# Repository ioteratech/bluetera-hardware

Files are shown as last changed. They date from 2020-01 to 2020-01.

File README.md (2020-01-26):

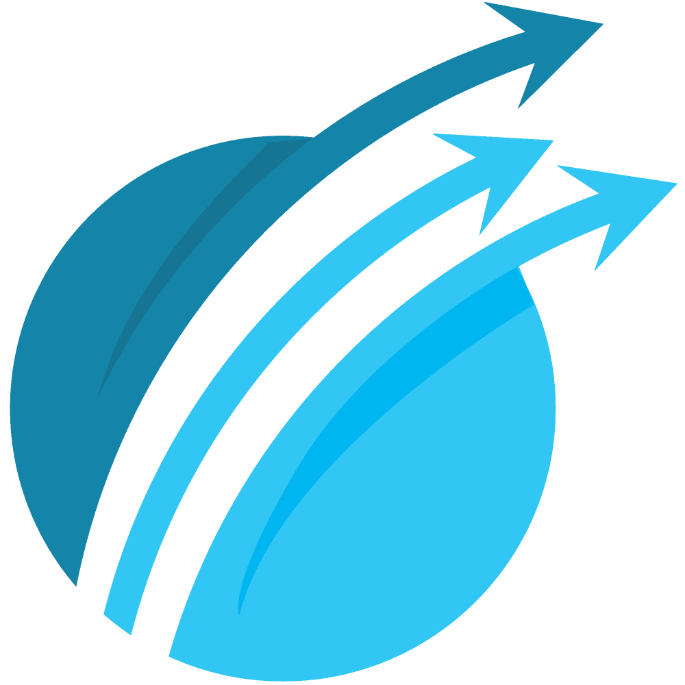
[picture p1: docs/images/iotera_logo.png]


# Bluetera Hardware

This repository contains the KiCad project for the Bluetera II and it's breakout adapter.

Bluetera is an open source IoT platform for the development of smart and connected products. The platform includes:
* Bluetera Hardware module (this repository)
* Bluetera Firmware - repository [here](https://github.com/ioteratech/bluetera-firmware)
* Blutera SDK(s) - repositories [here](https://github.com/ioteratech/)

More info available at our website: https://ioteratech.com

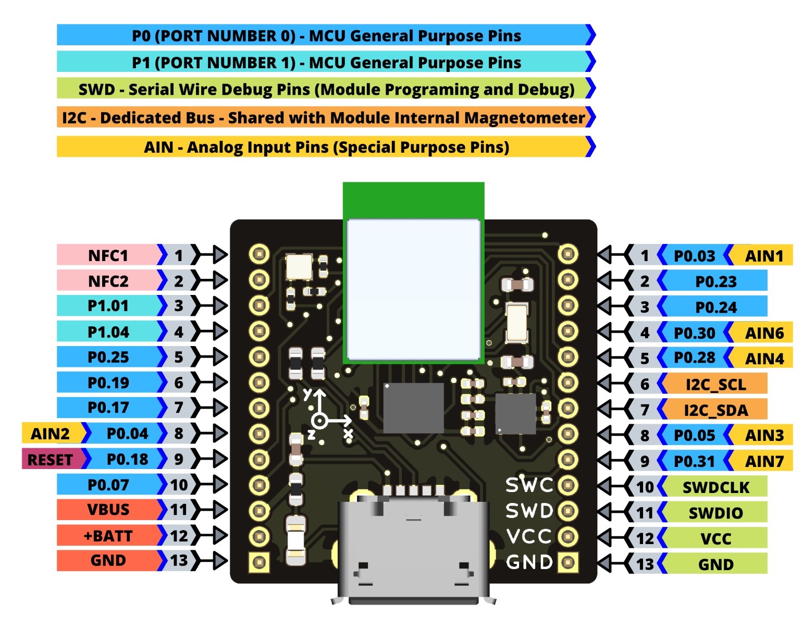
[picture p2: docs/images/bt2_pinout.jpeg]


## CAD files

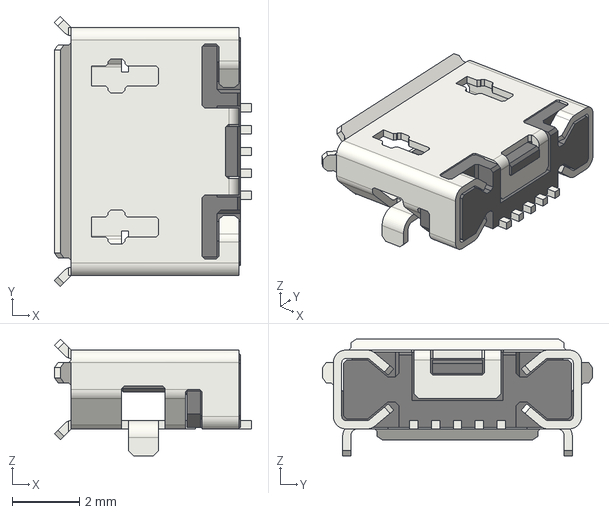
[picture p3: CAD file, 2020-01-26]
3d/Conn_USB-micro-2.0_socket_right-angle.step
5.88 x 8.05 x 3.47 mm

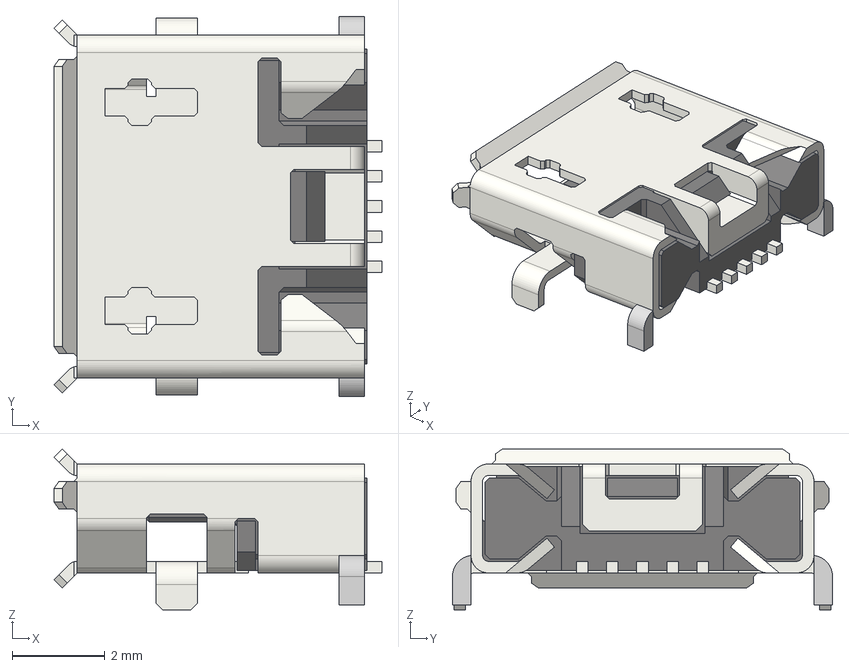
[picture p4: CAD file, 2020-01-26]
3d/Conn_USB-micro-2.step
7.07 x 8.20 x 3.47 mm

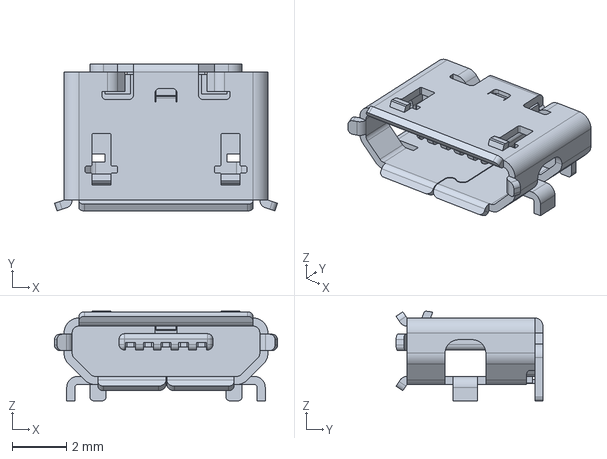
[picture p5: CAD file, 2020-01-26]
3d/Molex_Mirco_USB_105017-0001.step
8.20 x 5.40 x 3.30 mm

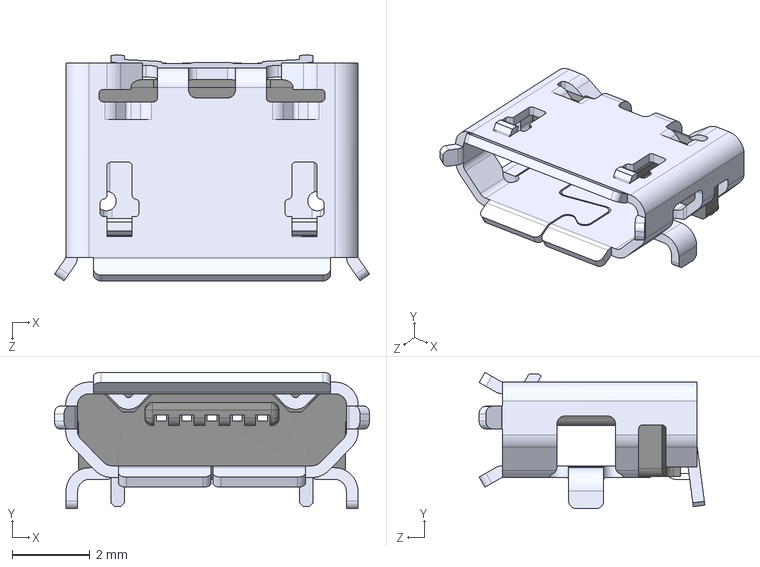
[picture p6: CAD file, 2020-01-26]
3d/ZX62D-B-5P8--3DModel-STEP-56544.STEP
8.09 x 3.50 x 5.80 mm

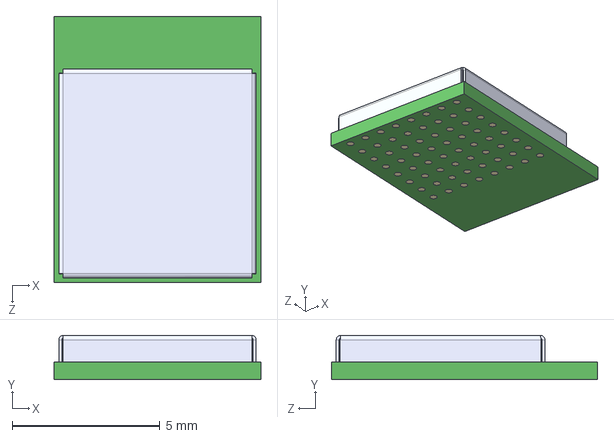
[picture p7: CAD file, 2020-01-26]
3d/BC840--3DModel-STEP-56544.STEP
7.00 x 1.50 x 9.00 mm

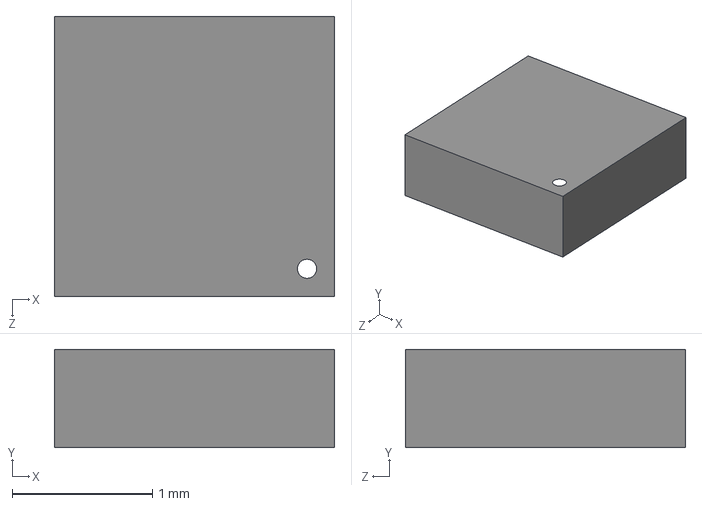
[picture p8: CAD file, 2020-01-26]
3d/IIS2MDCTR--3DModel-STEP-56544.STEP
2.00 x 0.7 x 2.00 mm

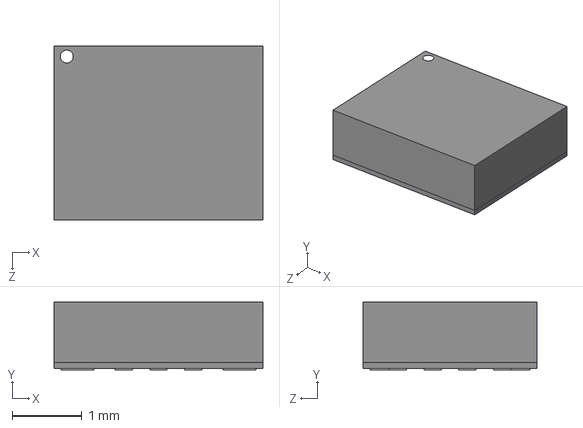
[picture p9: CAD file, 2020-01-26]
3d/ICM-42605--3DModel-STEP-1.STEP
3.00 x 0.97 x 2.50 mm

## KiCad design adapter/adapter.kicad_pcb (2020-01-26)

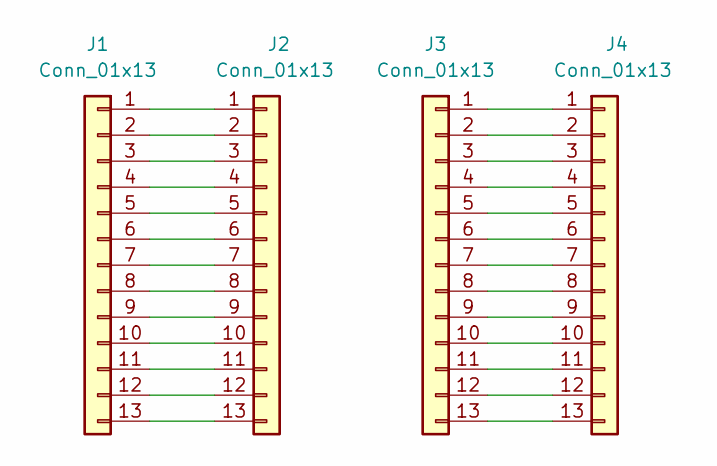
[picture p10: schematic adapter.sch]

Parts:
J1, J4: Conn_01x13; PinHeader_1x13_P2.54mm_Vertical
J2, J3: Conn_01x13; PinHeader_1x13_P1.27mm_Vertical

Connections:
unnamed: J1.1, J2.1
unnamed: J1.2, J2.2
unnamed: J1.3, J2.3
unnamed: J1.4, J2.4
unnamed: J1.5, J2.5
unnamed: J1.6, J2.6
unnamed: J1.7, J2.7
unnamed: J1.8, J2.8
unnamed: J1.9, J2.9
unnamed: J1.10, J2.10
unnamed: J1.11, J2.11
unnamed: J1.12, J2.12
unnamed: J1.13, J2.13
unnamed: J3.1, J4.1
unnamed: J3.2, J4.2
unnamed: J3.3, J4.3
unnamed: J3.4, J4.4
unnamed: J3.5, J4.5
unnamed: J3.6, J4.6
unnamed: J3.7, J4.7
unnamed: J3.8, J4.8
unnamed: J3.9, J4.9
unnamed: J3.10, J4.10
unnamed: J3.11, J4.11
unnamed: J3.12, J4.12
unnamed: J3.13, J4.13

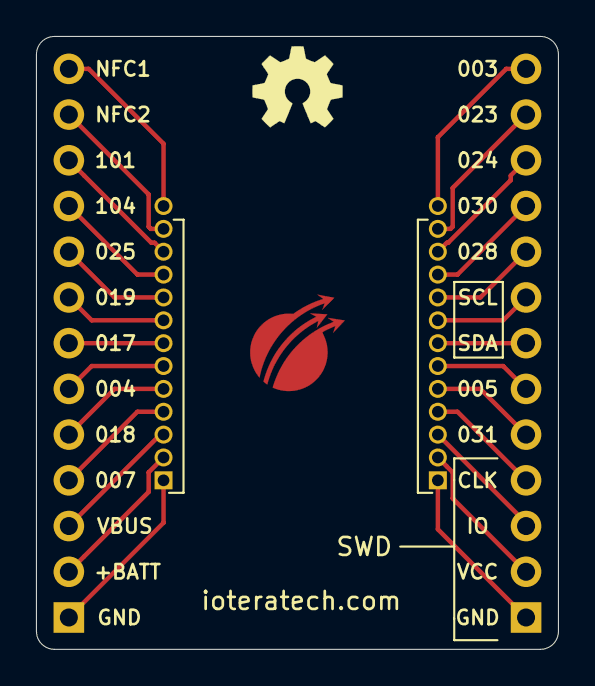
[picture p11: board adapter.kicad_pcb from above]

Board: 2 copper layers, 29.0 x 34.0 mm, 4 parts (0 on the bottom side), 26 nets.

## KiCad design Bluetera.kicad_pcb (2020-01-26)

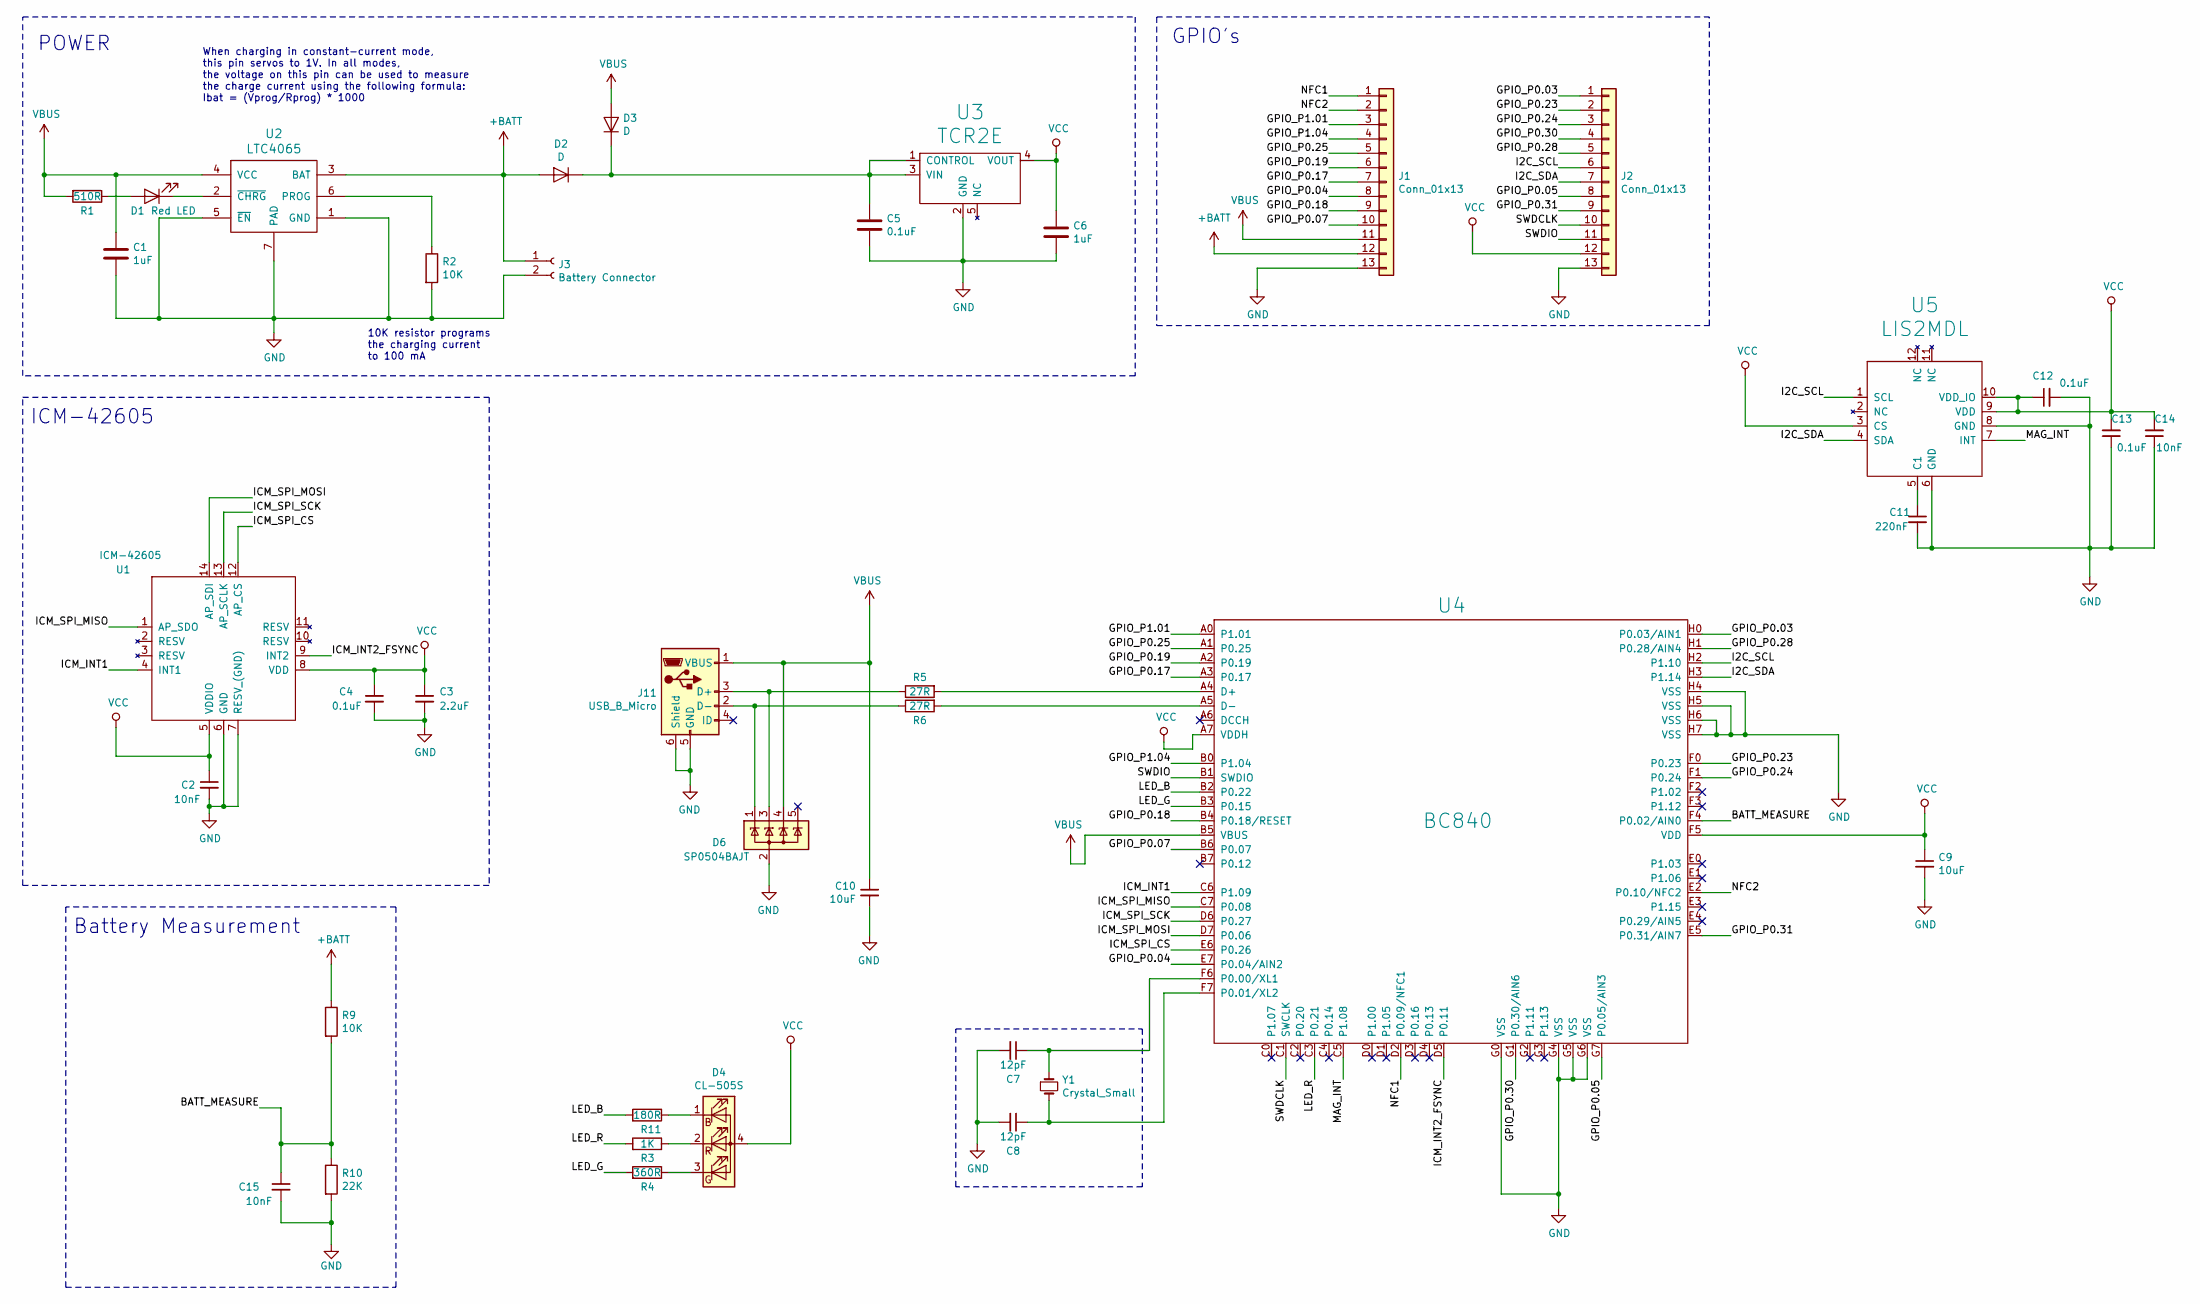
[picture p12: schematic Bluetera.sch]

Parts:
C1, C6: 1uF; C_0402_1005Metric; PartNumber C0402C105K9PACTU; DigikeyPartNumber 399-4873-1-ND
C2, C14: 10nF; C_0201_0603Metric; PartNumber CC0201KRX5R7BB103; DigikeyPartNumber 311-1596-1-ND
C3: 2.2uF; C_0201_0603Metric; PartNumber GRM033D80E225ME47D; DigikeyPartNumber 490-18653-1-ND
C4, C12, C13: 0.1uF; C_0201_0603Metric; PartNumber GRM033R61A104ME15D; DigikeyPartNumber 490-5405-1-ND
C5: 0.1uF; C_0402_1005Metric; PartNumber CL05F104ZO5NNNC; DigikeyPartNumber 1276-1004-1-ND
C7, C8: 12pF; C_0402_1005Metric; PartNumber CC0402JRNPO9BN120; DigikeyPartNumber 311-1016-1-ND
C9, C10: 10uF; C_0402_1005Metric; PartNumber GRM155C80J106ME11J; DigikeyPartNumber 490-18210-1-ND
C11: 220nF; C_0201_0603Metric; PartNumber CC0201MRX5R5BB224; DigikeyPartNumber 311-1412-1-ND
C15: 10nF; C_0402_1005Metric; PartNumber CC0201KRX5R7BB103; DigikeyPartNumber 311-1596-1-ND
D1: Red LED; LED_0603_1608Metric; PartNumber 150060RS75000; DigikeyPartNumber 732-4978-1-ND
D2, D3: D; D_SOD-523; PartNumber RB521S30T1G; DigikeyPartNumber RB521S30T1GOSCT-ND
D4: CL-505S; HSMF-C116; PartNumber CL-505S-X-SD-T; DigikeyPartNumber 1642-1510-1-ND
D6: SP0504BAJT; SOT-353_SC-70-5; PartNumber SP0504BAJTG; DigikeyPartNumber F3159CT-ND
J1, J2: Conn_01x13; PinHeader_1x13_P1.27mm_Vertical
J3: Battery Connector; JST_SH_SM02B-SRSS-TB_1x02-1MP_P1.00mm_Horizontal; PartNumber SM02B-SRSS-TB(LF)(SN); DigikeyPartNumber 455-1802-1-ND
J11: USB_B_Micro; USB_Micro-B; PartNumber 10118194-0001LF; DigikeyPartNumber 609-4618-1-ND
R1: 510R; R_0402_1005Metric; PartNumber ERJ-2BQJR51X; DigikeyPartNumber P17352CT-ND
R2, R9: 10K; R_0402_1005Metric; PartNumber RC0402FR-0710KL; DigikeyPartNumber 311-10.0KLRCT-ND
R3: 1K; R_0201_0603Metric; PartNumber RC0201FR-071KL; DigikeyPartNumber 311-1KMCT-ND
R4: 360R; R_0201_0603Metric; PartNumber RC0201FR-07360RL; DigikeyPartNumber YAG2622CT-ND
R5, R6: 27R; R_0402_1005Metric; PartNumber ERJ-2RKF27R0X; DigikeyPartNumber P27.0LCT-ND
R10: 22K; R_0402_1005Metric; PartNumber CRGCQ0402F22K; DigikeyPartNumber A129643CT-ND
R11: 180R; R_0201_0603Metric; PartNumber RC0201FR-07180RL; DigikeyPartNumber YAG2450CT-ND
U1: ICM-42605; PartNumber ICM-42605; DigikeyPartNumber 1428-1152-1-ND
U2: LTC4065; DFN-6-1EP_2x2mm_P0.5mm_EP0.61x1.42mm; PartNumber LTC4065AEDC#TRMPBF; DigikeyPartNumber LTC4065AEDC#TRMPBFCT-ND
U3: TCR2E; SOT-553; PartNumber TCR2EE30,LM(CT; DigikeyPartNumber TCR2EE30LM(CTCT-ND
U4: BC840
U5: LIS2MDL; PQFN50P200X200X70-12N; PartNumber LIS2MDLTR; DigikeyPartNumber 497-17588-1-ND
Y1: Crystal_Small; Crystal_SMD_2012-2Pin_2.0x1.2mm; PartNumber ECS-.327-9-12R-TR; DigikeyPartNumber XC2745CT-ND

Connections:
+BATT: D2.2 (A), J1.12, J3.1, R9.1, U2.3 (BAT)
/BATT_MEASURE: C15.1, R9.2, R10.1, U4.F4 (P0.02/AIN0)
/GPIO_P0.03: J2.1, U4.H0 (P0.03/AIN1)
/GPIO_P0.04: J1.8, U4.E7 (P0.04/AIN2)
/GPIO_P0.05: J2.8, U4.G7 (P0.05/AIN3)
/GPIO_P0.07: J1.10, U4.B6 (P0.07)
/GPIO_P0.17: J1.7, U4.A3 (P0.17)
/GPIO_P0.18: J1.9, U4.B4 (P0.18/RESET)
/GPIO_P0.19: J1.6, U4.A2 (P0.19)
/GPIO_P0.23: J2.2, U4.F0 (P0.23)
/GPIO_P0.24: J2.3, U4.F1 (P0.24)
/GPIO_P0.25: J1.5, U4.A1 (P0.25)
/GPIO_P0.28: J2.5, U4.H1 (P0.28/AIN4)
/GPIO_P0.30: J2.4, U4.G1 (P0.30/AIN6)
/GPIO_P0.31: J2.9, U4.E5 (P0.31/AIN7)
/GPIO_P1.01: J1.3, U4.A0 (P1.01)
/GPIO_P1.04: J1.4, U4.B0 (P1.04)
/I2C_SCL: J2.6, U4.H2 (P1.10), U5.1 (SCL)
/I2C_SDA: J2.7, U4.H3 (P1.14), U5.4 (SDA)
/ICM_INT1: U1.4 (INT1), U4.C6 (P1.09)
/ICM_INT2_FSYNC: U1.9 (INT2), U4.D5 (P0.11)
/ICM_SPI_CS: U1.12 (AP_CS), U4.E6 (P0.26)
/ICM_SPI_MISO: U1.1 (AP_SDO), U4.C7 (P0.08)
/ICM_SPI_MOSI: U1.14 (AP_SDI), U4.D7 (P0.06)
/ICM_SPI_SCK: U1.13 (AP_SCLK), U4.D6 (P0.27)
/LED_B: R11.2, U4.B2 (P0.22)
/LED_G: R4.2, U4.B3 (P0.15)
/LED_R: R3.2, U4.C3 (P0.21)
/MAG_INT: U4.C5 (P1.08), U5.7 (INT)
/NFC1: J1.1, U4.D2 (P0.09/NFC1)
/NFC2: J1.2, U4.E2 (P0.10/NFC2)
/SWDCLK: J2.10, U4.C1 (SWCLK)
/SWDIO: J2.11, U4.B1 (SWDIO)
GND: C1.2, C2.2, C3.2, C4.2, C5.2, C6.2, C7.2, C8.2, C9.2, C10.2, C11.2, C12.2, C13.1, C14.1, C15.2, D6.2 (A), J1.13, J2.13, J3.2, J11.5 (GND), J11.6 (Shield), R2.2, R10.2, U1.6 (GND), U1.7 (RESV_(GND)), U2.1 (GND), U2.5 (~EN), U2.7 (PAD), U3.2 (GND), U4.G0 (VSS), U4.G4 (VSS), U4.G5 (VSS), U4.G6 (VSS), U4.H4 (VSS), U4.H5 (VSS), U4.H6 (VSS), U4.H7 (VSS), U5.6 (GND), U5.8 (GND)
unnamed: C5.1, D2.1 (K), D3.1 (K), U3.1 (CONTROL), U3.3 (VIN)
unnamed: C7.1, U4.F6 (P0.00/XL1), Y1.1
unnamed: C8.1, U4.F7 (P0.01/XL2), Y1.2
unnamed: C11.1, U5.5 (C1)
unnamed: D1.1 (K), U2.2 (~CHRG)
unnamed: D1.2 (A), R1.1
unnamed: D4.1 (BK), R11.1
unnamed: D4.2 (RK), R3.1
unnamed: D4.3 (GK), R4.1
unnamed: D6.1 (K), J11.2 (D-), R6.1
unnamed: D6.3 (K), J11.3 (D+), R5.1
unnamed: R2.1, U2.6 (PROG)
unnamed: R5.2, U4.A4 (D+)
unnamed: R6.2, U4.A5 (D-)
VBUS: C1.1, C10.1, D3.2 (A), D6.4 (K), J1.11, J11.1 (VBUS), R1.2, U2.4 (VCC), U4.B5 (VBUS)
VCC: C2.1, C3.1, C4.1, C6.1, C9.1, C12.1, C13.2, C14.2, D4.4 (A), J2.12, U1.5 (VDDIO), U1.8 (VDD), U3.4 (VOUT), U4.A7 (VDDH), U4.F5 (VDD), U5.3 (CS), U5.9 (VDD), U5.10 (VDD_IO)

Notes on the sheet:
ICM-42605
10K resistor programs the charging current to 100 mA
When charging in constant-current mode, this pin servos to 1V. In all modes, the voltage on this pin can be used to measure the charge current using the following formula: Ibat = (Vprog/Rprog) * 1000
GPIO's
Battery Measurement
POWER

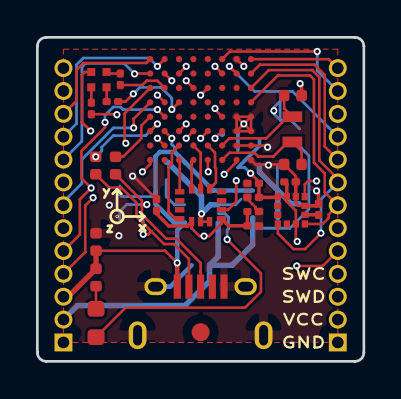
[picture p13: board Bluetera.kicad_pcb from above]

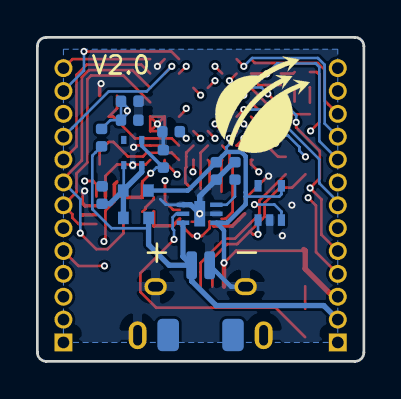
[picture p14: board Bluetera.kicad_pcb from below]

Board: 4 copper layers, 18.1 x 18.0 mm, 39 parts (16 on the bottom side), 50 nets.
